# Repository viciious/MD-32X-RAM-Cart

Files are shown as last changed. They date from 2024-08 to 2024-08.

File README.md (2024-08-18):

# MD-32X-RAM-Cart

A 4MiB RAM cart design for the Sega Genesis/Megadrive and the 32X.

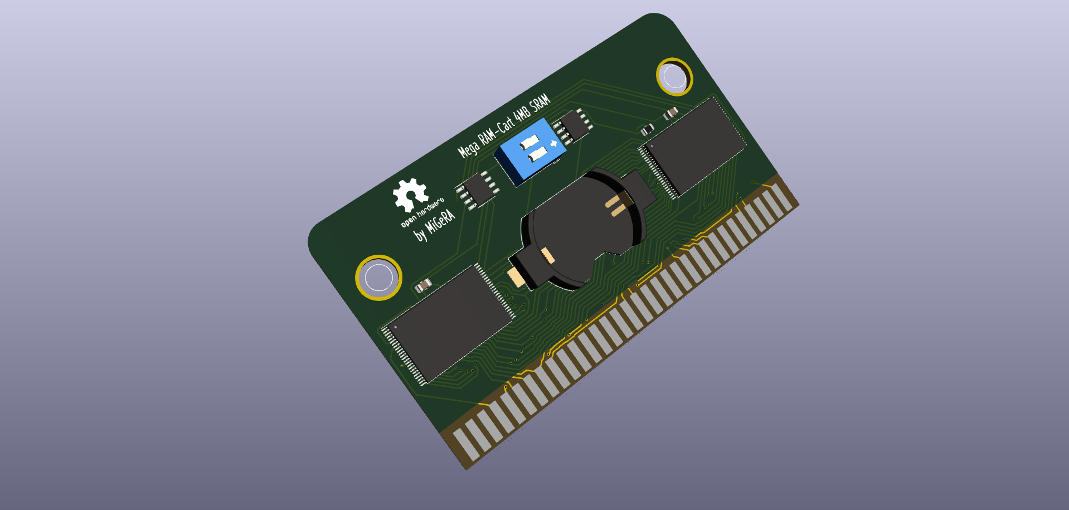
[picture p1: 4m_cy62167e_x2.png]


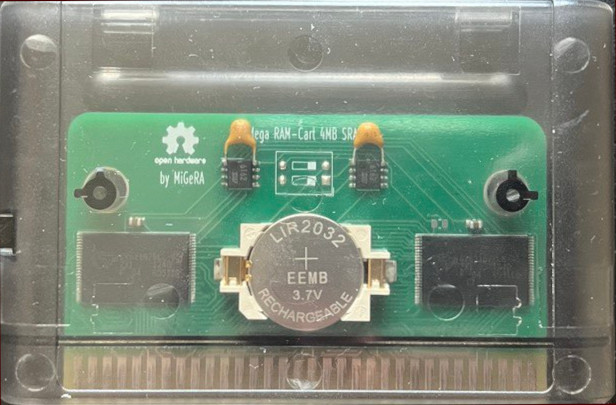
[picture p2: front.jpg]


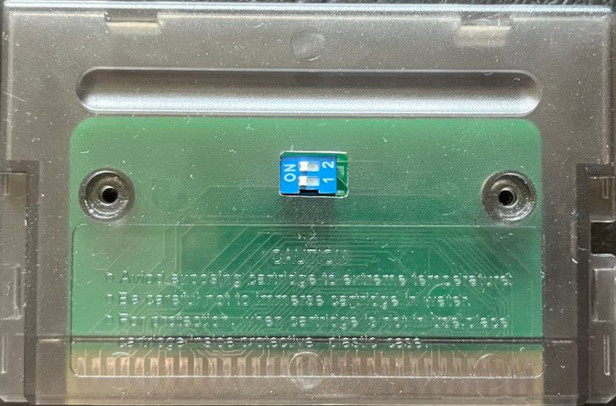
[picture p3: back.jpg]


Currently only works as MD RAM cart as reading data from the 32X causes data corruption.

Based on the original design by Tiido.

More info:
https://gendev.spritesmind.net/forum/viewtopic.php?f=4&t=1265

## Copyright and Disclaimer

Copyright: [MiGeRA](https://github.com/MiGeRA) (aka Th.K)

This documentation describes Open Hardware and is licensed under the CERN OHL v. 1.2.

You may redistribute and modify this documentation under the terms of the CERN OHL v.1.2. (http://ohwr.org/cernohl). This documentation is distributed WITHOUT ANY EXPRESS OR IMPLIED WARRANTY, INCLUDING OF MERCHANTABILITY, SATISFACTORY QUALITY AND FITNESS FOR A PARTICULAR PURPOSE. Please see the CERN OHL v.1.2 for applicable conditions

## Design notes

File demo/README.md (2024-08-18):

# ROM Loader for the Mega 32X RAM Cart

This project shows an example of how to load files onto the 4MiB RAM cart. 

## Description

Make sure the lower switch on the cart is set to "boot off the CD" position. Write the ISO file of this project to a CD-R and boot using the SegaCD addon.

After initial loading, the program will list files it was able to find on the CD. Select a ROM file from the CD and press A to write it onto the RAM cart. Pressing B will verify ROM/RAM contents with the selected file.

To boot off the previously written ROM, you need to toggle the lower switch to the off position and power cycle the console. Pressing the RESET button on the console will not work!

## "ROM Loader for the Mega 32X RAM Cart" Credits
* Programming : Chilly Willy and Victor Luchits
* Base Docker Code : Victor Luchits
## 

## License
All original code is available under the MIT license.

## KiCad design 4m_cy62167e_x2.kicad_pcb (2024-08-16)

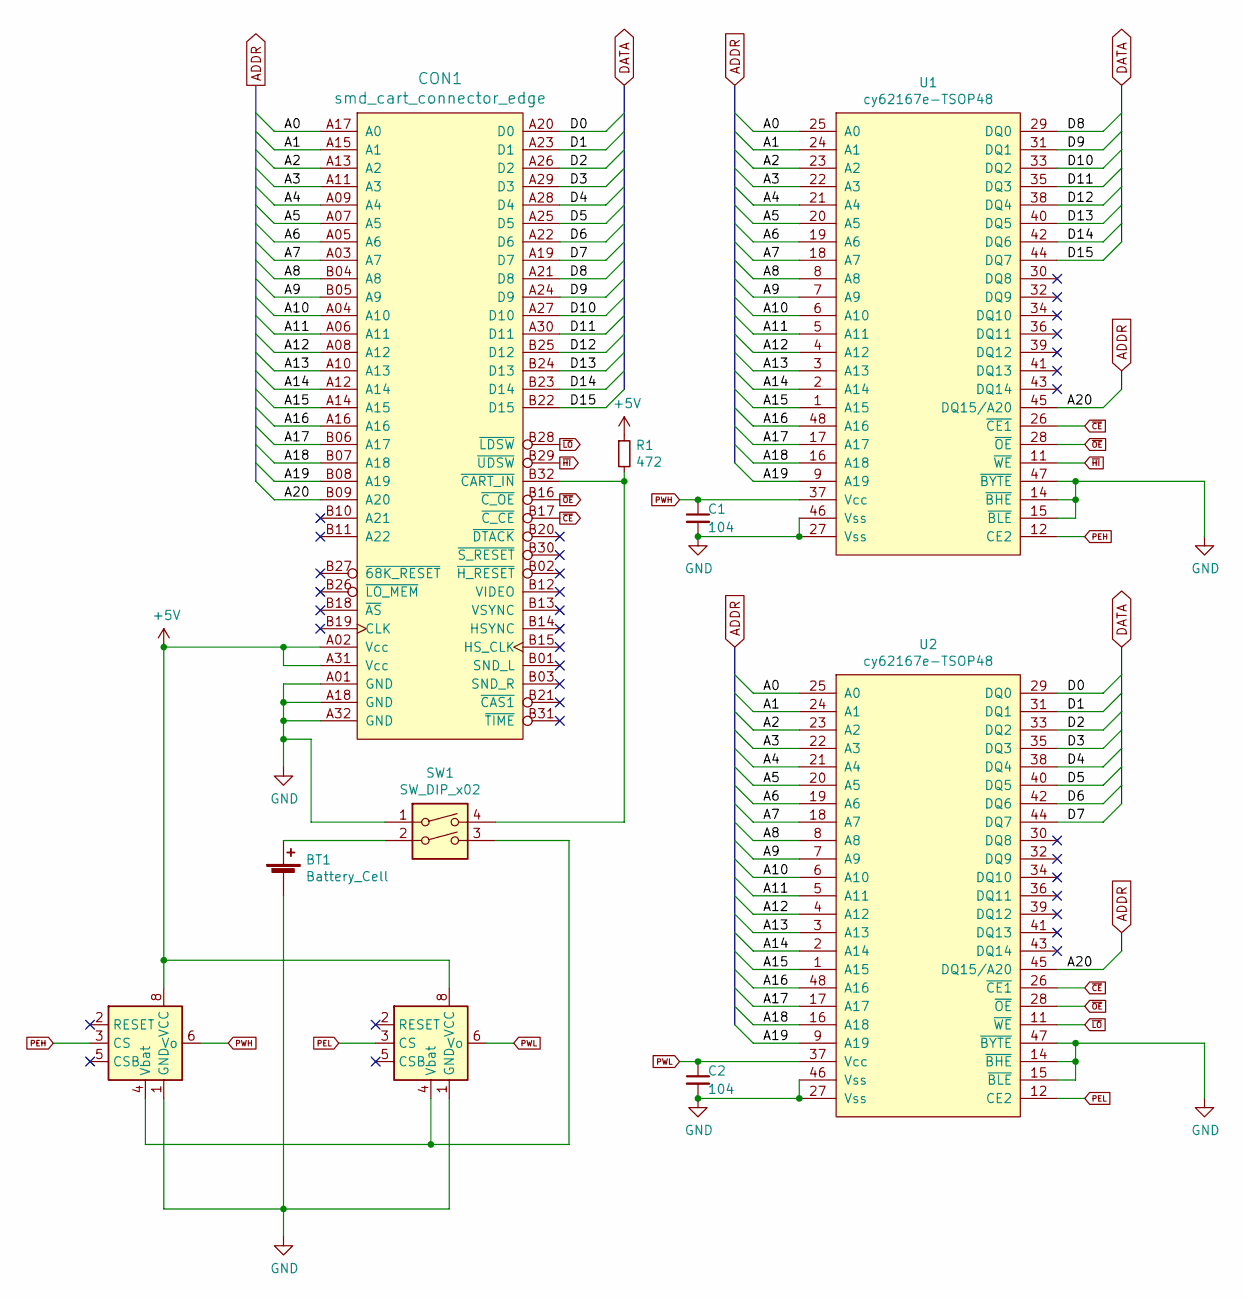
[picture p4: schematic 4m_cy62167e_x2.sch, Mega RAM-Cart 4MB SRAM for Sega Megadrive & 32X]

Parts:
BT1: Battery_Cell; BatteryHolder_Keystone_1058_1x2032
C1, C2: 104; C_0805_2012Metric
CON1: smd_cart_connector_edge; md_cart_edge_conn
R1: 472; R_0805_2012Metric
SW1: SW_DIP_x02; SW_DIP_SPSTx02_Slide_9.78x7.26mm_W7.62mm_P2.54mm
U1, U2: cy62167e-TSOP48; TSOP-I-48
U3, U4: BA6162; SSOP-8_3.9x5.05mm_P1.27mm

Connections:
+5V: CON1.A02 (Vcc), CON1.A31 (Vcc), R1.1, U3.8 (VCC), U4.8 (VCC)
/A0: CON1.A17 (A0), U1.25 (A0), U2.25 (A0)
/A1: CON1.A15 (A1), U1.24 (A1), U2.24 (A1)
/A2: CON1.A13 (A2), U1.23 (A2), U2.23 (A2)
/A3: CON1.A11 (A3), U1.22 (A3), U2.22 (A3)
/A4: CON1.A09 (A4), U1.21 (A4), U2.21 (A4)
/A5: CON1.A07 (A5), U1.20 (A5), U2.20 (A5)
/A6: CON1.A05 (A6), U1.19 (A6), U2.19 (A6)
/A7: CON1.A03 (A7), U1.18 (A7), U2.18 (A7)
/A8: CON1.B04 (A8), U1.8 (A8), U2.8 (A8)
/A9: CON1.B05 (A9), U1.7 (A9), U2.7 (A9)
/A10: CON1.A04 (A10), U1.6 (A10), U2.6 (A10)
/A11: CON1.A06 (A11), U1.5 (A11), U2.5 (A11)
/A12: CON1.A08 (A12), U1.4 (A12), U2.4 (A12)
/A13: CON1.A10 (A13), U1.3 (A13), U2.3 (A13)
/A14: CON1.A12 (A14), U1.2 (A14), U2.2 (A14)
/A15: CON1.A14 (A15), U1.1 (A15), U2.1 (A15)
/A16: CON1.A16, U1.48 (A16), U2.48 (A16)
/A17: CON1.B06 (A17), U1.17 (A17), U2.17 (A17)
/A18: CON1.B07 (A18), U1.16 (A18), U2.16 (A18)
/A19: CON1.B08 (A19), U1.9 (A19), U2.9 (A19)
/A20: CON1.B09 (A20), U1.45 (DQ15/A20), U2.45 (DQ15/A20)
/D0: CON1.A20 (D0), U2.29 (DQ0)
/D1: CON1.A23 (D1), U2.31 (DQ1)
/D2: CON1.A26 (D2), U2.33 (DQ2)
/D3: CON1.A29 (D3), U2.35 (DQ3)
/D4: CON1.A28 (D4), U2.38 (DQ4)
/D5: CON1.A25 (D5), U2.40 (DQ5)
/D6: CON1.A22 (D6), U2.42 (DQ6)
/D7: CON1.A19 (D7), U2.44 (DQ7)
/D8: CON1.A21 (D8), U1.29 (DQ0)
/D9: CON1.A24 (D9), U1.31 (DQ1)
/D10: CON1.A27 (D10), U1.33 (DQ2)
/D11: CON1.A30 (D11), U1.35 (DQ3)
/D12: CON1.B25 (D12), U1.38 (DQ4)
/D13: CON1.B24 (D13), U1.40 (DQ5)
/D14: CON1.B23 (D14), U1.42 (DQ6)
/D15: CON1.B22 (D15), U1.44 (DQ7)
GND: BT1.2 (-), C1.2, C2.2, CON1.A01 (GND), CON1.A18 (GND), CON1.A32 (GND), SW1.1, U1.14 (~BHE), U1.15 (~BLE), U1.27 (Vss), U1.46 (Vss), U1.47 (~BYTE), U2.14 (~BHE), U2.15 (~BLE), U2.27 (Vss), U2.46 (Vss), U2.47 (~BYTE), U3.1 (GND), U4.1 (GND)
unnamed: BT1.1 (+), SW1.2
unnamed: CON1.B32 (~CART_IN), R1.2, SW1.4
unnamed: SW1.3, U3.4 (Vbat), U4.4 (Vbat)
PEH: U1.12 (CE2), U3.3 (CS)
PEL: U2.12 (CE2), U4.3 (CS)
PWH: C1.1, U1.37 (Vcc), U3.6 (Vo)
PWL: C2.1, U2.37 (Vcc), U4.6 (Vo)
~CE: CON1.B17 (~C_CE), U1.26 (~CE1), U2.26 (~CE1)
~HI: CON1.B29 (~UDSW), U1.11 (~WE)
~LO: CON1.B28 (~LDSW), U2.11 (~WE)
~OE: CON1.B16 (~C_OE), U1.28 (~OE), U2.28 (~OE)

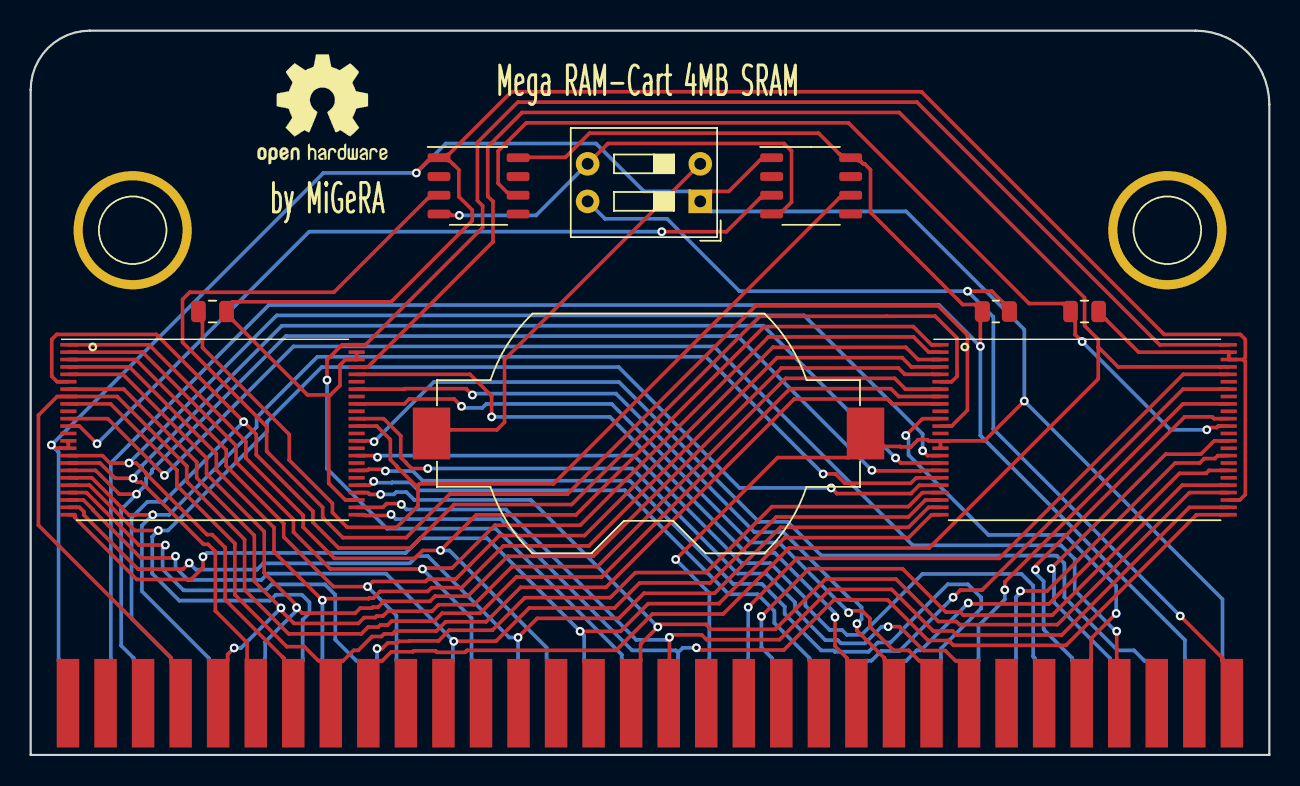
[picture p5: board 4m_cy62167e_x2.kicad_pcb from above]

Board: 2 copper layers, 83.8 x 49.0 mm, 12 parts (0 on the bottom side), 50 nets.

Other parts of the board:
DRL1, DRL2: 1pin

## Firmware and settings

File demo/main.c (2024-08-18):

#include <stdint.h>
#include <stdio.h>
#include <stdlib.h>
#include <string.h>

#include "hw_md.h"

#define MAX_ENTRIES 256

typedef struct
{
    int offset;
    int length;
    char flags;
    char name[247];
} entry_t;

entry_t gDirTable[MAX_ENTRIES];

short gCount = 0;
short gFirst = 0;
short gCurrent = 0;
short gStage = 0;

char *temp = (char *)0x0C0000;
char *rom_start = (void*)0x400000;

//----------------------------------------------------------------------

int getCurrDir(void)
{
    int r = 0;
    int i = 0;

    while (!r)
    {
        r = next_dir_entry();
        if (!r && memcmp(global_vars->DENTRY_NAME, ".", 2))
        {
            gDirTable[i].offset = global_vars->DENTRY_OFFSET;
            gDirTable[i].length = global_vars->DENTRY_LENGTH;
            gDirTable[i].flags = global_vars->DENTRY_FLAGS >> 8;
            strcpy(gDirTable[i].name, global_vars->DENTRY_NAME);
            i++;
        }

        if (r == ERR_NO_MORE_ENTRIES)
            r = next_dir_sec();
    }

    return i;
}

void transfer(char *temp)
{
    int i, j;
    int length;
    int block, offset;

    length = gDirTable[gCurrent].length;
    offset = gDirTable[gCurrent].offset;

    for (i = 0; i < length; )
    {
        int chunk = 0x20000;
        int m68kchunk = 0x4000;

        if (i + chunk > length)
            chunk = length - i;

        sprintf(temp, "Loading %08X-%08X\n", i, i+chunk);
        switch_banks();
        do_md_cmd4(MD_CMD_PUT_STR, 0x200000, TEXT_GREEN, 1, 24);

        block = (i >> 11) + offset;
        read_cd(block, (chunk + 0x7FF) >> 11, temp);
#ifndef BUF_TEST
        switch_banks();
#endif
        for (j = 0; j < chunk; ) {
            if (j + m68kchunk > chunk)
                m68kchunk = chunk - j;
#ifndef BUF_TEST
            do_md_cmd3(MD_CMD_CPY_MD, (intptr_t)rom_start+i+j, 0x200000+j, m68kchunk);
#else
            memcpy(buf+i+j, temp+j, m68kchunk);
#endif
            j += m68kchunk;
        }

        i += chunk;
    }

    strcpy(temp, "OK                                     ");
    switch_banks();
    do_md_cmd4(MD_CMD_PUT_STR, 0x200000, TEXT_GREEN, 1, 24);
}

void verify(char *temp)
{
    int i, j;
    int mismatch = 0;
    int length, offset, block;

    length = gDirTable[gCurrent].length;
    offset = gDirTable[gCurrent].offset;

    for (i = 0; i < length; )
    {
        int chunk = 0x10000;
        int m68kchunk = 0x4000;
        volatile char *temp2 = temp + 0x10000;

        if (i + chunk > length)
            chunk = length - i;

        sprintf(temp, "Verifying %07X-%07X\n", i, i+chunk);
        switch_banks();
        do_md_cmd4(MD_CMD_PUT_STR, 0x200000, TEXT_GREEN, 1, 24);

        block = (i >> 11) + offset;
        read_cd(block, (chunk + 0x7FF) >> 11, temp);

        switch_banks();

        for (j = 0; j < chunk; ) {
            if (j + m68kchunk > chunk)
                m68kchunk = chunk - j;

            do_md_cmd3(MD_CMD_CPY_MD, 0x200000+0x10000+j, (intptr_t)rom_start+i+j, m68kchunk);

            j += m68kchunk;
        }

        switch_banks();

        for (j = 0; j < chunk; j++)
        {
            if (temp[j] != temp2[j])
            {
                int c1 = temp[j]&0xff;
                int c2 = temp2[j]&0xff;
                mismatch = 1;
                sprintf(temp, "Mismatch %07X %02X/%02X  \n", i+j, c1, c2);
                switch_banks();
                do_md_cmd4(MD_CMD_PUT_STR, 0x200000, TEXT_GREEN, 1, 24);
                break;
            }
        }

        if (mismatch)
            break;

        i += chunk;
    }

    if (!mismatch)
    {
        strcpy(temp, "OK                                     ");
        switch_banks();
        do_md_cmd4(MD_CMD_PUT_STR, 0x200000, TEXT_GREEN, 1, 24);
    }
}

int main(void)
{
    int i, j;
    unsigned short buttons, changed, previous = 0;

    strcpy(temp, "ROM Player");
    switch_banks();
    do_md_cmd4(MD_CMD_PUT_STR, 0x200000, TEXT_WHITE, 15, 1);

    init_cd(); // init CD
    set_cwd("/"); // set current directory to root
    gCount = getCurrDir();

    gStage = 0;

    while (1)
    {

        if (gStage == 0)
        {
 
            char *p = temp;

            // update display with directory entries
            memset(p, 0, 20*64*2);
            if (gCount)
                for (i = 0; i < 20; i++)
                {
                    if ((gFirst + i) >= gCount)
                        break;

                    p = &temp[i*64*2 + 2]; // left justified
                    if (gDirTable[gFirst + i].flags & 2)
                    {
                        // directory
                        *p++ = ((gFirst + i) == gCurrent) ? TEXT_WHITE >> 8 : TEXT_GREEN >> 8;
                        *p++ = '[' - 0x20;
                        for (j = 0; j < 36; j++)
                        {
                            if (gDirTable[gFirst + i].name[j] == '\0')
                                break;
                            *p++ = ((gFirst + i) == gCurrent) ? TEXT_WHITE >> 8 : TEXT_GREEN >> 8;
                            *p++ = gDirTable[gFirst + i].name[j] - 0x20;
                        }
                        *p++ = ((gFirst + i) == gCurrent) ? TEXT_WHITE >> 8 : TEXT_GREEN >> 8;
                        *p++ = ']' - 0x20;
                    }
                    else
                    {
                        for (j = 0; j < 38; j++)
                        {
                            if (gDirTable[gFirst + i].name[j] == '\0')
                                break;
                            *p++ = ((gFirst + i) == gCurrent) ? TEXT_WHITE >> 8 : TEXT_GREEN >> 8;
                            *p++ = gDirTable[gFirst + i].name[j] - 0x20;
                        }
                    }
                }
            switch_banks();
            sub_delay(1); // wait until vblank to update vram
            i = do_md_cmd3(MD_CMD_COPY_VRAM, 0xC000 + 3*64*2, 0x200000, 20*64); // update plane A name table (20 lines of text)
            if (i < 0)
            {
                if (i == -1)
                    strcpy(temp, "unknown command");
                else if (i == -2)
                    strcpy(temp, "wait cmd done timeout");
                else if (i == -3)
                    strcpy(temp, "wait cmd ack timeout");
                else
                    strcpy(temp, "unknown error");
                switch_banks();
                do_md_cmd4(MD_CMD_PUT_STR, 0x200000, TEXT_RED, 1, 24);
                sub_delay(120);
                strcpy(temp, "                                       ");
                switch_banks();
                do_md_cmd4(MD_CMD_PUT_STR, 0x200000, TEXT_GREEN, 1, 24);
            }

            sub_delay(7);

            gStage = 1;

        } 
        else if (gStage == 1)
        {

            buttons = GET_PAD(0);

            changed = (buttons & SEGA_CTRL_BUTTONS) ^ previous;

            if (buttons & SEGA_CTRL_DOWN)
            {
                // DOWN pressed
                gCurrent++;
                if ((gCurrent - gFirst) >= 20)
                    gFirst = gCurrent;

                if (gCurrent >= gCount)
                    gFirst = gCurrent = 0; // wrap around to first entry

                gStage = 0;

            }

            if (buttons & SEGA_CTRL_UP)
            {

                // UP pressed
                gCurrent--;
                if (gCurrent < gFirst)
                {
                    gFirst = gCurrent - 19;
                    if (gFirst < 0)
                        gFirst = 0;
                }

                if (gCurrent < 0)
                {
                    gCurrent = gCount - 1; // wrap around to last entry
                    gFirst = gCurrent - 19;
                    if (gFirst < 0)
                        gFirst = 0;
                }

                gStage = 0;

            }

            if (!changed)
                continue; // no change in buttons
            previous = buttons & SEGA_CTRL_BUTTONS;

            if (changed & SEGA_CTRL_A)
            {
                if (!(buttons & SEGA_CTRL_A))
                {
                    // A just released
                    if (gDirTable[gCurrent].flags & 2)
                    {
                        // directory
                        global_vars->CWD_OFFSET = gDirTable[gCurrent].offset;
                        global_vars->CWD_LENGTH = gDirTable[gCurrent].length;
                        global_vars->CURR_OFFSET = -1;
                        first_dir_sec();
                        gCount = getCurrDir();
                        gFirst = gCurrent = 0;
                        gStage = 0;
                    }
                    else
                    {
                        transfer(temp);
                    }
                }
            }

            if (changed & SEGA_CTRL_B)
            {
                if (!(buttons & SEGA_CTRL_B))
                {
                    // B just released
                    if (gDirTable[gCurrent].flags & 2)
                    {
                        // directory
                    }
                    else
                    {
                        verify(temp);
                    }
                }
            }
        }
    
    }

    return 0;
}

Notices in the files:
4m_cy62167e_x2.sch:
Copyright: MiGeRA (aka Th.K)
